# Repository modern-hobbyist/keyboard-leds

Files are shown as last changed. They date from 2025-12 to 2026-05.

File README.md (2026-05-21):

# 🎹 Piano Keyboard LED Visualizer (WIP)

This project is a **custom RP2040-based LED controller** designed to add **reactive RGB lighting** to a piano or MIDI keyboard by reading the incoming **MIDI stream** and driving high-density LED strips.

This is my second iteration of MIDI-driven keyboard LEDs, but the first time going *all in* with a fully custom PCB, power-path management, and an onboard touchscreen UI.

⚠️ **Status:** Work in progress  
Hardware is under active development, firmware and features are evolving, and this README will be updated as the project matures.

---

## ✨ High-Level Overview

- Reads **MIDI input** from a keyboard or computer
- Visualizes notes and velocity using **addressable RGB LEDs**
- Includes a **touchscreen UI** for configuring colors, brightness, and animations
- Designed to safely handle **high LED current** while remaining USB-compliant when connected to a computer

The long-term goal is to make this a flexible platform for experimenting with different LED visualization styles while keeping the hardware robust and reusable.

---

## 🔧 Hardware Overview

### Core Components
- **MCU:** RP2040
- **External Flash:** Winbond **W25Q128JVS** (16 MB)
- **Display:** 2.8″ 320×240 TFT LCD with touch
- **LED Support:**  
  - Designed for ~**1–1.5 m of 144 px/m LED strips**
  - Intended for per-key piano illumination

### USB & Power Architecture
- **USB-C (Data / MIDI / Firmware Flashing)**
- **USB-C (Dedicated LED Power Input)**
- **TPS2121** – automatic power-path switching between USB sources
- **TUSB320** – USB-C CC controller used to determine available current
- **Polyfuses** on both USB inputs for protection

The board is designed to intelligently decide how much LED brightness is safe depending on the power source.

---

## 🎯 Design Goals

- **Dual-mode operation**
  - Plugged into a computer → automatically limit LED current to stay within USB limits (~500 mA)
  - Plugged into a keyboard’s MIDI output + external USB-C PSU → allow much higher LED brightness (~3 A target)
- **Touchscreen UI**
  - Adjust brightness, colors, and animations
  - Switch visualization modes without a computer
- **High LED density support**
  - Enough bandwidth and power to drive dense LED strips cleanly
- **Expandable firmware**
  - External flash provides room for animations, fonts, and UI assets

Exact feature set is still evolving — the focus right now is getting the hardware and power logic correct.

---

## 📌 GPIO Pin Map

### SPI Bus — ILI9341 Display + XPT2046 Touch (shared)
| GPIO | Net | Function |
|---|-----|---|
| 16 | LCD_MISO | SPI MISO |
| 18 | LCD_SCK | SPI clock |
| 19 | LCD_MOSI | SPI MOSI |
| 17 | LCD_CS | ILI9341 chip select |
| 20 | LCD_DC | ILI9341 data/command |
| 21 | LCD_RST | ILI9341 reset |
| 22 | LCD_BL_PWM | Backlight PWM |
| 13 | LCD_T_CS | XPT2046 touch chip select |
| 12 | LCD_T_IRQ | XPT2046 touch interrupt |
| 14 | LCD_SD_CS | SD card chip select (LCD module) |

### I2C Bus — Power Management ICs
| GPIO | Net | Function |
|---|-----|---|
| 4 | SDA | I2C data (TUSB320) |
| 5 | SCL | I2C clock (TUSB320) |

### LEDs & Power Control
| GPIO | Net | Function |
|---|-----|---|
| 6 | RGB3.3 | SK6812 data → level shifter → 5 V strip |
| 3 | DIM_DATA | TPS2121 dimming/current limit control |
| 8 | POWER_INT | Interrupt from power management IC |

### USB
| Signal | Function |
|---|---|
| USB D+ / D− | Data USB-C — MIDI host + firmware flashing |

### QSPI Flash
Managed automatically by MicroPython. Connected to the W25Q128JVS via the RP2040's dedicated QSPI pins (not accessible as general GPIO).

---

## 🧠 Firmware

MicroPython firmware is included in the `firmware/` directory. See [`firmware/README.md`](firmware/README.md) for full setup and flashing instructions.

**Features:**
- USB MIDI host — keyboard plugs directly into the data USB-C port
- SK6812 LED animations: velocity, rainbow, sustain, single color, gradient
- ILI9341 touchscreen UI with scrollable settings menu
- Persistent settings saved to flash (brightness, animation mode, MIDI channel, LED count, etc.)
- Brightness limiting via TPS2121 `DIM_DATA` line based on available power

**Requirements:** MicroPython ≥ 1.24 for RP2040 with `usb.host` support.

---

## 🧩 PCB Review Context

This board uses a few parts that are new to me, particularly for USB-C and power management:

- **TUSB320** – for USB-C current detection
- **TPS2121** – for seamless power-path switching

While I’ve built multiple custom mechanical keyboards, this is my first design combining:
- Dual USB-C inputs
- High LED current
- USB-compliant behavior
- Onboard display + touch

Feedback on **power logic, USB-C usage, and general robustness** is especially appreciated.

---

## 📦 Bill of Materials (BOM)

A complete BOM is included in the repo and reflects the current PCB revision.  
Key highlights:
- RP2040 MCU
- W25Q128JVS external flash
- TPS2121 power mux
- TUSB320 USB-C controller
- SRV05-4 ESD protection
- TFT LCD (ILI9341-based)

⚠️ Component values and footprints may change as the design is reviewed and iterated.

---

## 📸 Media & Updates

I plan to document this project on my **YouTube channel, Modern Hobbyist**, including:
- PCB bring-up
- Power testing
- LED current experiments
- Firmware development

Links will be added as videos are published.

---

## 🤝 Feedback & Contributions

This repo is currently focused on **design review and learning**, but feedback is very welcome.

If you have experience with:
- USB-C power negotiation
- LED power distribution
- RP2040 display pipelines
- MIDI-driven lighting

…I’d love to hear your thoughts.

---

## 📄 License

TBD (will be added once the design stabilizes)

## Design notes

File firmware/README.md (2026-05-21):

# Keyboard LED Firmware

MicroPython firmware for the RP2040-based keyboard LED visualizer.

## Requirements

- **MicroPython ≥ 1.24** for RP2040 with `usb.host` compiled in
  ([download](https://micropython.org/download/RPI_PICO/))
- `neopixel` — built-in to MicroPython
- `framebuf`  — built-in to MicroPython

No third-party libraries are required.

## File layout

```
firmware/
  main.py      Entry point (copy all files to the Pico's root filesystem)
  pins.py      GPIO pin assignments (derived from the KiCad schematic)
  config.py    Settings load/save (persisted to settings.json in flash)
  leds.py      SK6812 LED controller + 5 animation modes
  display.py   ILI9341 SPI display driver (320×240, RGB565)
  touch.py     XPT2046 resistive touch driver
  midi.py      USB MIDI host input + REPL injection helper
  ui.py        Main view + settings menu
```

## Flashing

1. Download the MicroPython UF2 with USB host support for RP2040.
2. Hold BOOTSEL, plug in USB, release — Pico appears as a USB drive.
3. Drag the `.uf2` onto the drive.
4. Use `mpremote` (or Thonny) to copy all `firmware/*.py` to `/`:
   ```sh
   mpremote cp firmware/*.py :
   ```
5. The board will reboot and run `main.py` automatically.

## USB MIDI host

The RP2040 USB port acts as a **USB host**.  Plug your MIDI keyboard's USB
cable directly into the board's data USB-C port.  The firmware discovers the
first USB MIDI class interface automatically.

> **Note:** If your keyboard only has a 5-pin DIN MIDI output, you need a
> USB-MIDI adapter (e.g. Roland UM-ONE) between the DIN connector and the
> board, or connect via a computer running a MIDI bridge.

If `usb.host` is not available in your MicroPython build, the firmware still
boots.  Use the REPL to test without a keyboard:

```python
import midi
midi.inject(0x90, 60, 100)   # note-on middle C, velocity 100
midi.inject(0x80, 60, 0)     # note-off middle C
```

## Touch calibration

Run once after first boot if the touch is inaccurate:

```python
import touch, display, machine
from machine import SPI, Pin
import pins as P
spi = SPI(P.SPI_ID, baudrate=2_000_000, sck=Pin(P.SPI_SCK),
          mosi=Pin(P.SPI_MOSI), miso=Pin(P.SPI_MISO))
display.init(spi)
touch.init(spi)
vals = touch.calibrate()
print(vals)
```

Update `CAL_X_MIN/MAX`, `CAL_Y_MIN/MAX` at the top of `touch.py` with the
printed values.

## Settings

Saved to `settings.json` in the Pico's flash.  Editable at runtime via the
touchscreen Settings menu (tap **Settings** in the top-right corner of the
main screen).

| Key | Default | Description |
|---|---|---|
| `animation` | `velocity`  | `velocity`, `rainbow`, `sustain`, `single`, `gradient` |
| `brightness`  | `80` | LED brightness 0–255 |
| `sustain_ms`  | `500` | Note fade-out duration (sustain mode) |
| `midi_channel`| `0` | 0 = all channels, 1–16 = specific |
| `num_leds` | `144` | Number of LEDs in the strip |
| `note_offset` | `0` | Shift LED mapping ±20 positions |
| `color_h` | `200` | Hue for single-color mode (0–360) |
| `backlight` | `80` | LCD backlight percentage |

## Animation modes

| Mode | Description |
|---|---|
| `velocity` | Key position → hue, velocity → brightness (default) |
| `rainbow`  | Static rainbow; active notes flash white |
| `sustain`  | Notes fade out slowly after release |
| `single` | All active notes use the configured hue |
| `gradient` | Dim colour background; active notes show velocity hue |

MIDI Program Change messages (PC 0–4) also select animation modes in order.

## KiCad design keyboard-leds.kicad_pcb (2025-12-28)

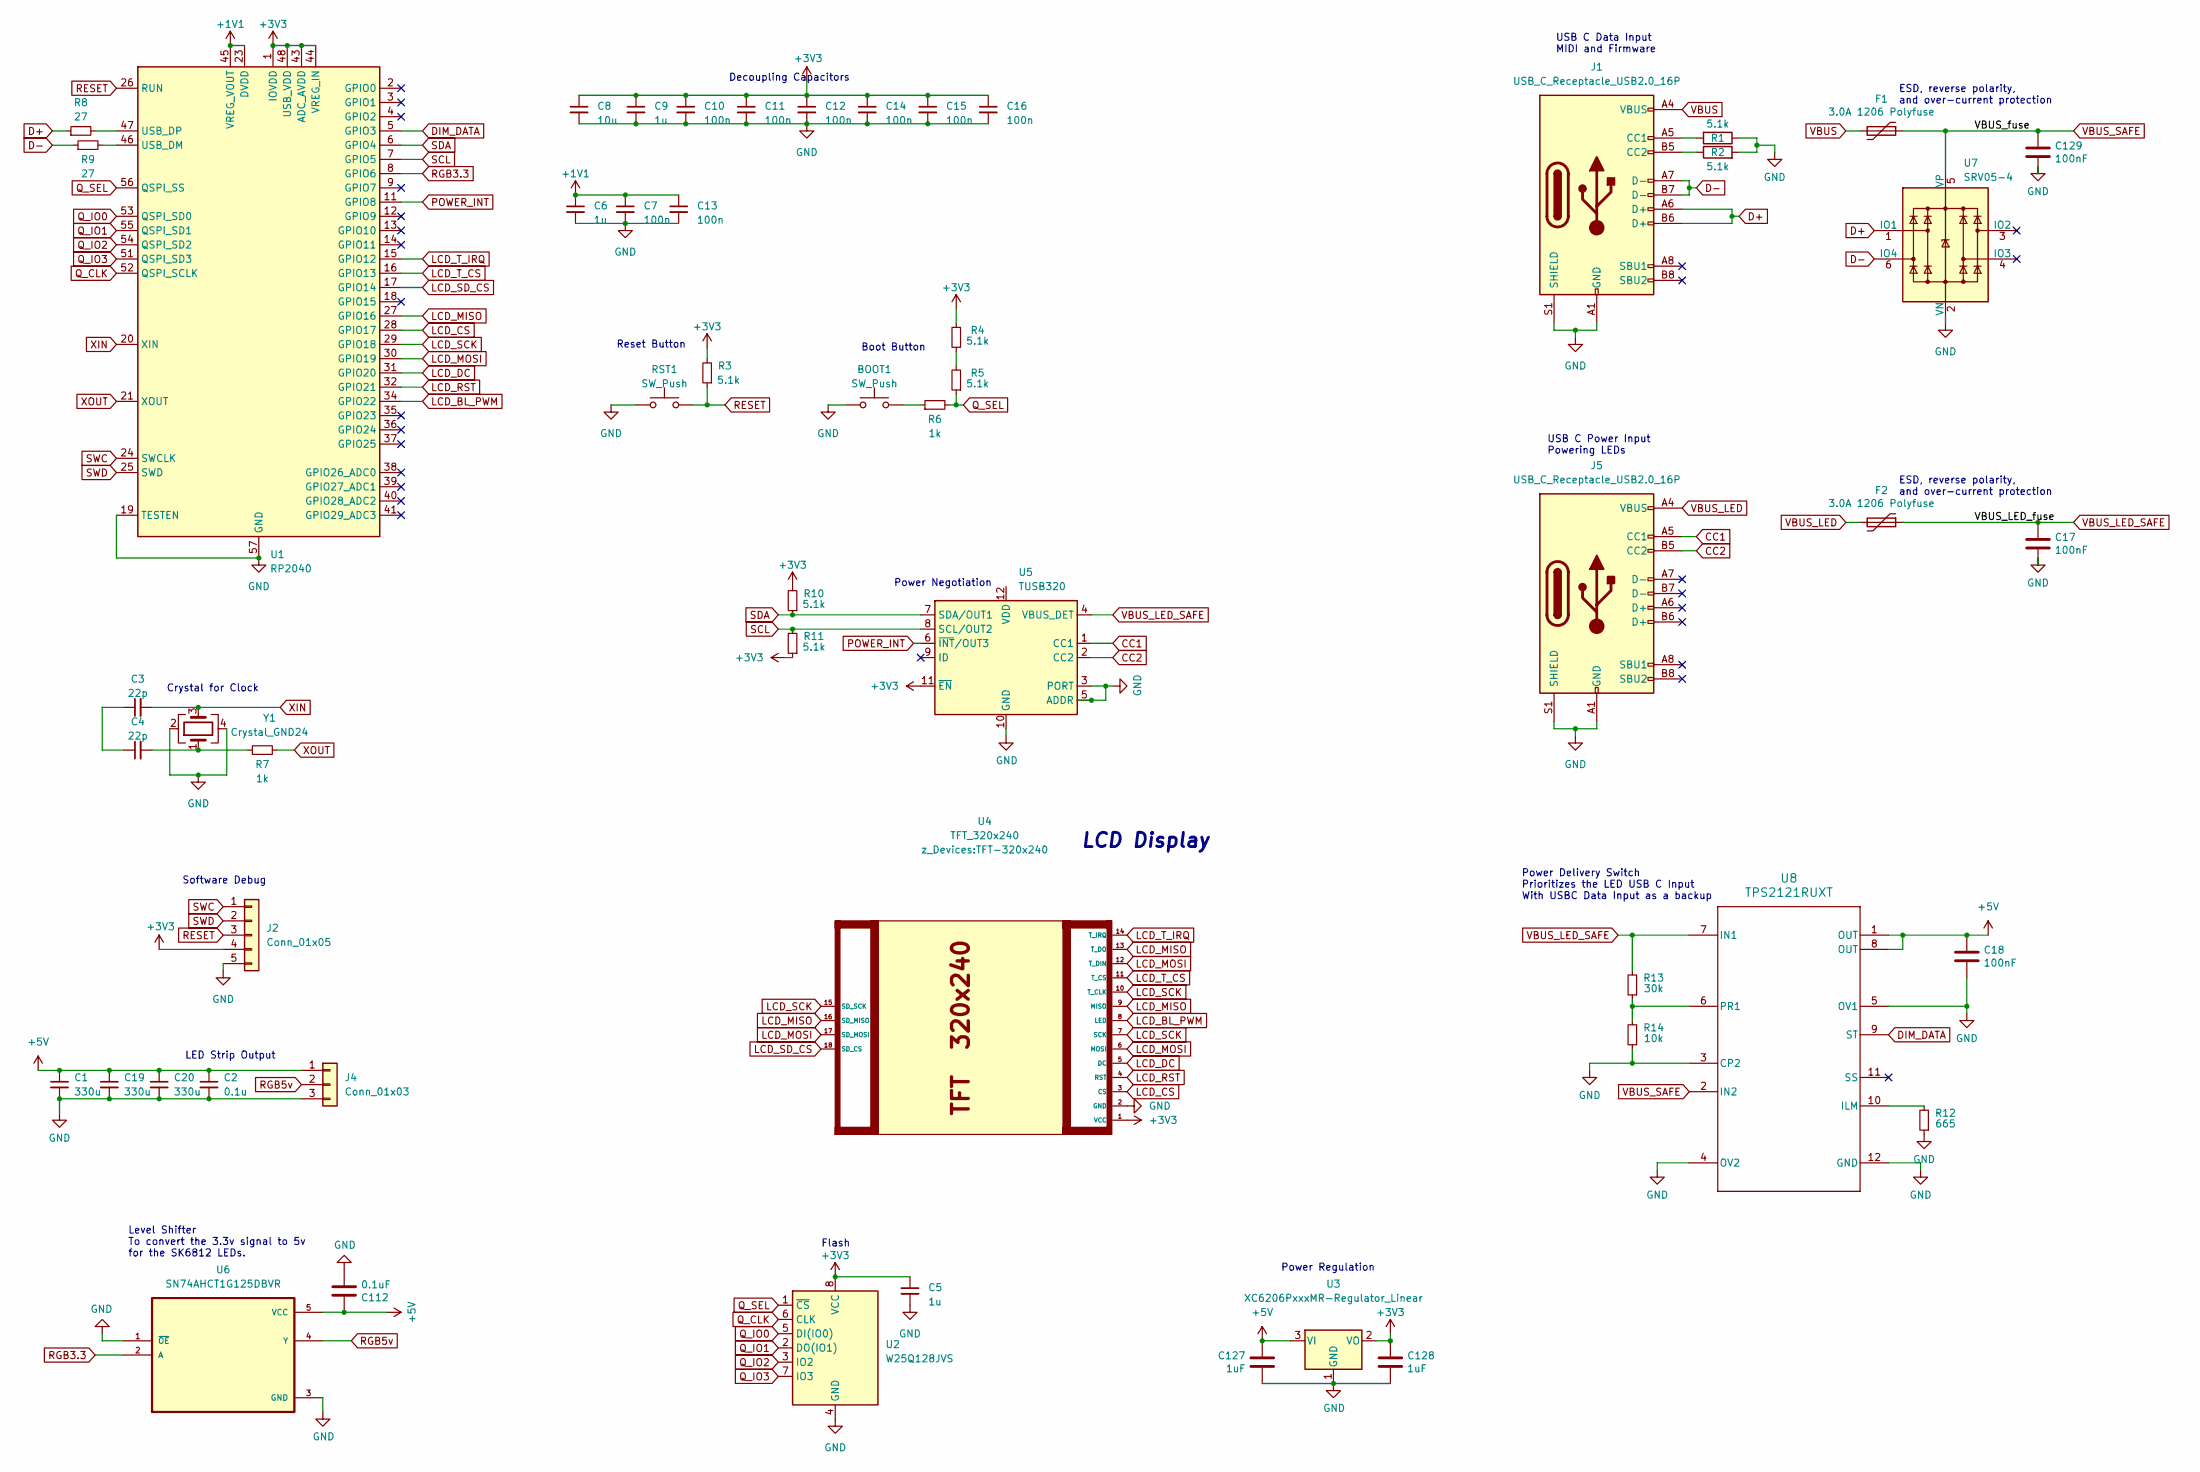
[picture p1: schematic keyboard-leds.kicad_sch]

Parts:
BOOT1: SW_Push; SW_SPST_TL3342
C1, C19, C20: 330u; CP_EIA-7343-31_Kemet-D
C2: 0.1u; C_0603_1608Metric
C3, C4: 22p; C_0402_1005Metric
C5, C6, C9: 1u; C_0402_1005Metric
C7, C10, C11, C12, C13, C14, C15, C16: 100n; C_0402_1005Metric
C8: 10u; C_0603_1608Metric
C17, C18, C129: 100nF; C_0402_1005Metric; LCSC C307331
C112: 0.1uF; C_0402_1005Metric; LCSC C307331
C127, C128: 1uF; C_0402_1005Metric; LCSC C307331
F1, F2: 3.0A 1206 Polyfuse; Fuse_1206_3216Metric
J1, J5: USB_C_Receptacle_USB2.0_16P; USB_C_Receptacle_HRO_TYPE-C-31-M-12
J2: Conn_01x05; PinHeader_1x05_P2.54mm_Vertical
J4: Conn_01x03; JST_XH_S3B-XH-A-1_1x03_P2.50mm_Horizontal
R1, R2, R3, R4, R5, R10, R11: 5.1k; R_0402_1005Metric
R6, R7: 1k; R_0402_1005Metric
R8, R9: 27; R_0402_1005Metric
R12: 665; R_0402_1005Metric
R13: 30k; R_0402_1005Metric
R14: 10k; R_0402_1005Metric
RST1: SW_Push; SW_SPST_TL3342
U1: RP2040; QFN-56-1EP_7x7mm_P0.4mm_EP3.2x3.2mm
U2: W25Q128JVS; SOIC-8_5.23x5.23mm_P1.27mm
U3: XC6206PxxxMR-Regulator_Linear; SOT-23; LCSC C5446
U4: TFT_320x240; TFT-320x240
U5: TUSB320; Texas_X2QFN-12_1.6x1.6mm_P0.4mm
U6: SN74AHCT1G125DBVR; SOT95P280X145-5N
U7: SRV05-4; SOT-23-6-routable
U8: TPS2121RUXT; RUX0012A
Y1: Crystal_GND24; Crystal_SMD_3225-4Pin_3.2x2.5mm

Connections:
+1V1: C6.1, C7.1, C13.1, U1.23 (DVDD), U1.45 (VREG_VOUT), U1.50 (DVDD)
+3V3: C5.1, C8.1, C9.1, C10.1, C11.1, C12.1, C14.1, C15.1, C16.1, C128.1, J2.4, R3.2, R4.2, R10.2, R11.1, U1.1 (IOVDD), U1.10 (IOVDD), U1.22 (IOVDD), U1.33 (IOVDD), U1.42 (IOVDD), U1.43 (ADC_AVDD), U1.44 (VREG_IN), U1.48 (USB_VDD), U1.49 (IOVDD), U2.8 (VCC), U3.2 (VO), U4.1 (VCC), U5.11 (~EN)
+5V: C1.1, C2.1, C18.1, C19.1, C20.1, C112.1, C127.1, J4.1, U3.3 (VI), U6.5 (VCC), U8.1 (OUT), U8.8 (OUT)
CC1: J5.A5 (CC1), U5.1 (CC1)
CC2: J5.B5 (CC2), U5.2 (CC2)
D+: J1.A6 (D+), J1.B6 (D+), R8.1, U7.1 (IO1)
D-: J1.A7 (D-), J1.B7 (D-), R9.1, U7.6 (IO4)
DIM_DATA: U1.5 (GPIO3), U8.9 (ST)
GND: BOOT1.1, C1.2, C2.2, C5.2, C6.2, C7.2, C8.2, C9.2, C10.2, C11.2, C12.2, C13.2, C14.2, C15.2, C16.2, C17.2, C18.2, C19.2, C20.2, C112.2, C127.2, C128.2, C129.2, J1.A1 (GND), J1.A12 (GND), J1.B1 (GND), J1.B12 (GND), J1.S1 (SHIELD), J2.5, J4.3, J5.A1 (GND), J5.A12 (GND), J5.B1 (GND), J5.B12 (GND), J5.S1 (SHIELD), R1.1, R2.2, R12.1, R14.1, RST1.1, U1.19 (TESTEN), U1.57 (GND), U2.4 (GND), U3.1 (GND), U4.2 (GND), U5.3 (PORT), U5.5 (ADDR), U5.10 (GND), U6.1 (~OE), U6.3 (GND), U7.2 (VN), U8.3 (CP2), U8.4 (OV2), U8.5 (OV1), U8.12 (GND), Y1.2, Y1.4
LCD_BL_PWM: U1.34 (GPIO22), U4.8 (LED)
LCD_CS: U1.28 (GPIO17), U4.3 (CS)
LCD_DC: U1.31 (GPIO20), U4.5 (DC)
LCD_MISO: U1.27 (GPIO16), U4.9 (MISO), U4.13 (T_DO), U4.16 (SD_MISO)
LCD_MOSI: U1.30 (GPIO19), U4.6 (MOSI), U4.12 (T_DIN), U4.17 (SD_MOSI)
LCD_RST: U1.32 (GPIO21), U4.4 (RST)
LCD_SCK: U1.29 (GPIO18), U4.7 (SCK), U4.10 (T_CLK), U4.15 (SD_SCK)
LCD_SD_CS: U1.17 (GPIO14), U4.18 (SD_CS)
LCD_T_CS: U1.16 (GPIO13), U4.11 (T_CS)
LCD_T_IRQ: U1.15 (GPIO12), U4.14 (T_IRQ)
unnamed: BOOT1.2, R6.1
unnamed: C3.1, C4.1
unnamed: C4.2, R7.1, Y1.1
unnamed: J1.A5 (CC1), R1.2
unnamed: J1.B5 (CC2), R2.1
unnamed: R4.1, R5.2
unnamed: R9.2, U1.46 (USB_DM)
unnamed: R8.2, U1.47 (USB_DP)
unnamed: R12.2, U8.10 (ILM)
unnamed: R13.1, R14.2, U8.6 (PR1)
POWER_INT: U1.11 (GPIO8), U5.6 (~INT/OUT3)
Q_CLK: U1.52 (QSPI_SCLK), U2.6 (CLK)
Q_IO0: U1.53 (QSPI_SD0), U2.5 (DI(IO0))
Q_IO1: U1.55 (QSPI_SD1), U2.2 (DO(IO1))
Q_IO2: U1.54 (QSPI_SD2), U2.3 (IO2)
Q_IO3: U1.51 (QSPI_SD3), U2.7 (IO3)
Q_SEL: R5.1, R6.2, U1.56 (QSPI_SS), U2.1 (~CS)
RESET: J2.3, R3.1, RST1.2, U1.26 (RUN)
RGB3.3: U1.8 (GPIO6), U6.2 (A)
RGB5v: J4.2, U6.4 (Y)
SCL: R11.2, U1.7 (GPIO5), U5.8 (SCL/OUT2)
SDA: R10.1, U1.6 (GPIO4), U5.7 (SDA/OUT1)
SWC: J2.1, U1.24 (SWCLK)
SWD: J2.2, U1.25 (SWD)
VBUS: F1.2, J1.A4 (VBUS), J1.A9 (VBUS), J1.B4 (VBUS), J1.B9 (VBUS)
VBUS_LED: F2.2, J5.A4 (VBUS), J5.A9 (VBUS), J5.B4 (VBUS), J5.B9 (VBUS)
VBUS_LED_SAFE: C17.1, F2.1, R13.2, U5.4 (VBUS_DET), U8.7 (IN1)
VBUS_SAFE: C129.1, F1.1, U7.5 (VP), U8.2 (IN2)
XIN: C3.2, U1.20 (XIN), Y1.3
XOUT: R7.2, U1.21 (XOUT)

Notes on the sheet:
LCD Display
Power Negotiation
Power Delivery Switch Prioritizes the LED USB C Input With USBC Data Input as a backup
Flash
Reset Button
USB C Data Input MIDI and Firmware
LED Strip Output
Crystal for Clock
Decoupling Capacitors
Level Shifter To convert the 3.3v signal to 5v for the SK6812 LEDs.
Boot Button
USB C Power Input Powering LEDs
Software Debug
ESD, reverse polarity, and over-current protection
Power Regulation

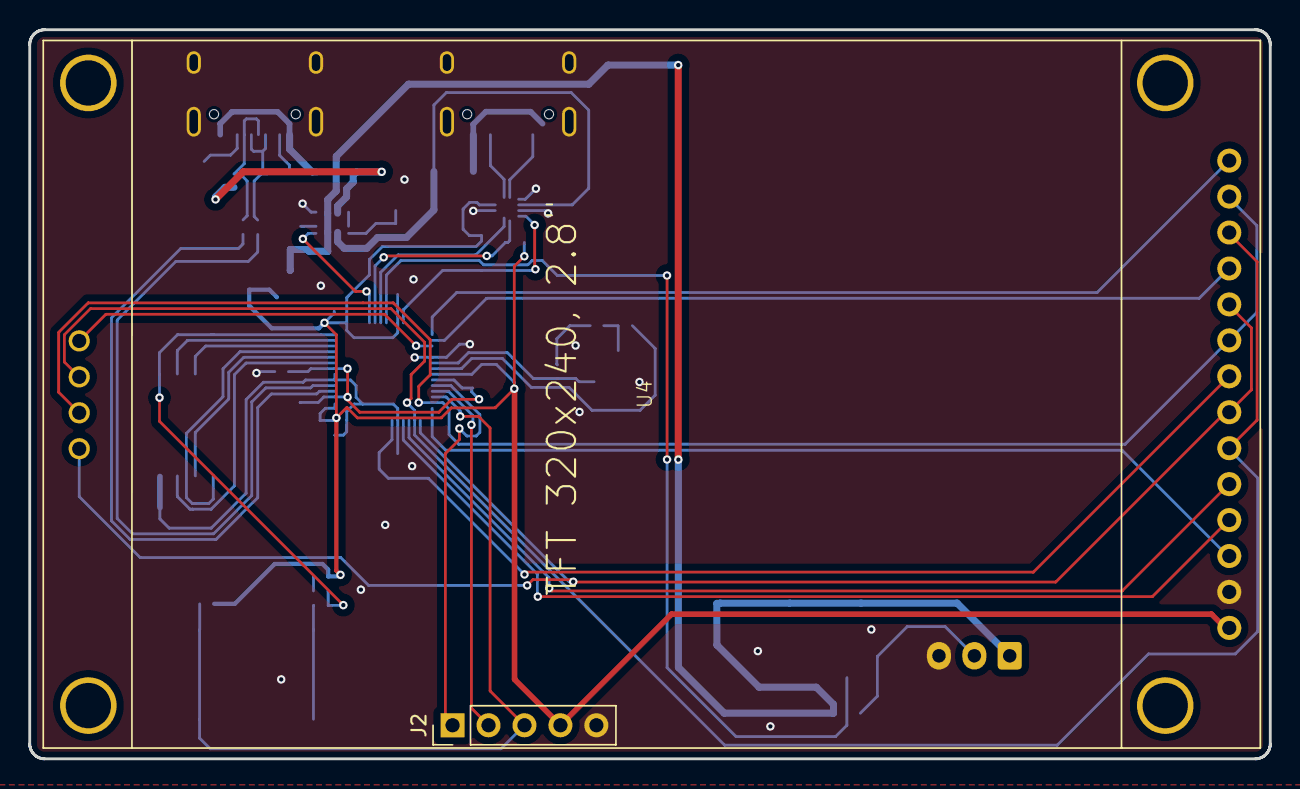
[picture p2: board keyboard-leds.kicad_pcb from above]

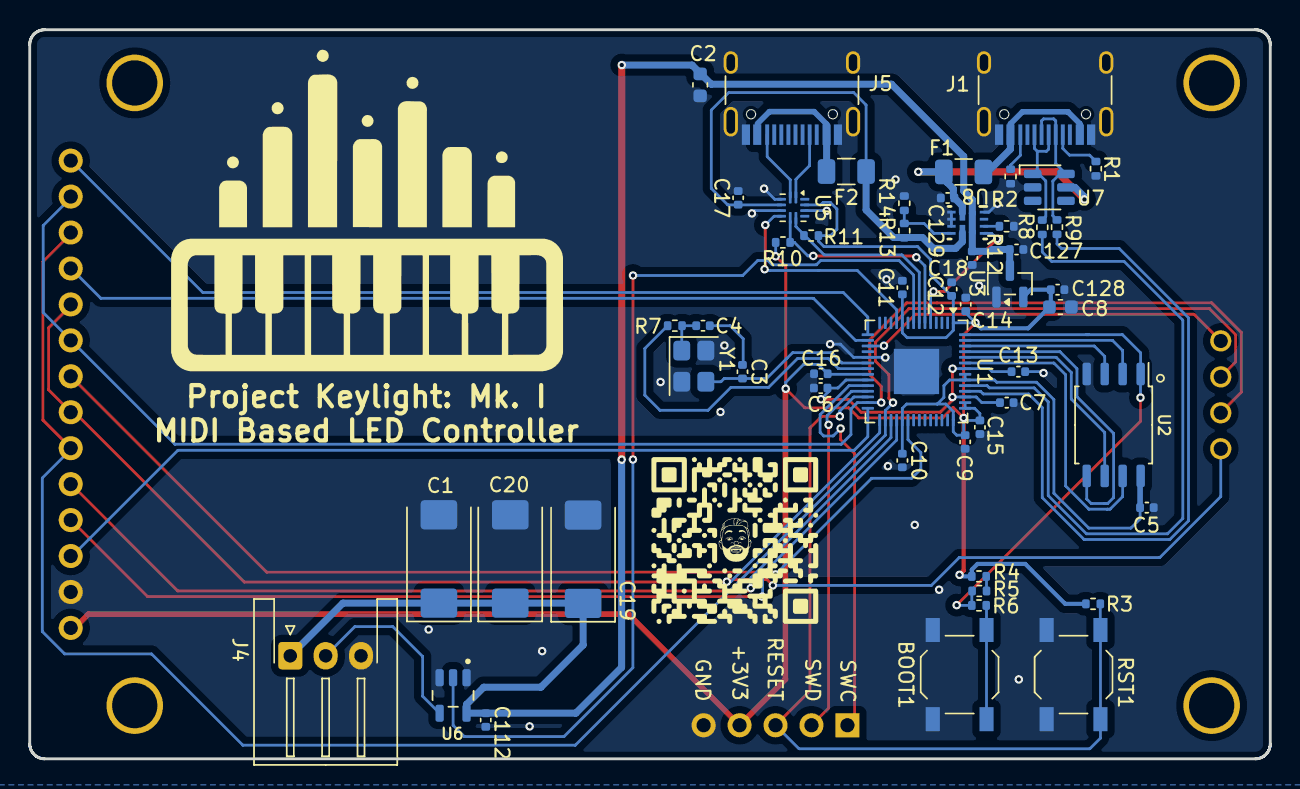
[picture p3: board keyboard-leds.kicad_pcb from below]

Board: 2 copper layers, 87.7 x 51.5 mm, 55 parts (53 on the bottom side), 49 nets.

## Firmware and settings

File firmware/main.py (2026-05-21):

"""
Keyboard LED Visualizer — main entry point.

Boot order:
  1. Load settings from flash
  2. Bring up SPI bus → ILI9341 display
  3. Init XPT2046 touch controller
  4. Init SK6812 LED strip
  5. Start USB MIDI host
  6. Show splash screen + LED test
  7. Enter main loop

USB MIDI host requires MicroPython ≥ 1.24 with usb.host compiled in.
If that module is absent the firmware still boots; use midi.inject() in
the REPL to send notes without a keyboard connected.

Quick REPL test:
  import midi
  midi.inject(0x90, 60, 100)   # note-on C4 vel=100
  midi.inject(0x80, 60, 0)     # note-off C4
"""

import time
from machine import Pin, SPI, I2C, PWM
import pins as P
import config
import leds
import display as d
import touch
import midi
import ui


# ---------------------------------------------------------------------------
# Initialisation
# ---------------------------------------------------------------------------

def _init_spi() -> SPI:
    # Display runs at 40 MHz; touch driver drops to 2 MHz while reading.
    spi = SPI(
        P.SPI_ID,
        baudrate=40_000_000,
        polarity=0,
        phase=0,
        sck=Pin(P.SPI_SCK),
        mosi=Pin(P.SPI_MOSI),
        miso=Pin(P.SPI_MISO),
    )
    return spi


def _init_power():
    """
    Configure the TPS2121 dimming line and set up the power-interrupt pin.

    DIM_DATA (GPIO3) drives the TPS2121 VOUT voltage, which controls maximum
    LED current.  Pull it high (3.3 V) to allow full brightness; the main loop
    can lower it based on POWER_INT feedback from the TUSB320.

    For now, assert high unconditionally and let the user tune via the
    brightness setting.  A proper implementation would read I2C registers from
    the TUSB320 and scale accordingly.
    """
    dim = Pin(P.DIM_DATA, Pin.OUT, value=1)
    power_irq = Pin(P.POWER_INT, Pin.IN, Pin.PULL_UP)
    return dim, power_irq


def _splash():
    bg = d.rgb(10, 10, 30)
    d.fill(bg)
    d.text("Keyboard LEDs",     60, 80,  d.WHITE, bg, scale=2)
    d.text("by Modern Hobbyist", 60, 120, d.GRAY,  bg, scale=1)
    d.text("Booting...",        60, 150, d.GRAY,  bg, scale=1)


# ---------------------------------------------------------------------------
# MIDI callbacks
# ---------------------------------------------------------------------------

def _on_note_on(channel: int, note: int, velocity: int):
    leds.note_on(note, velocity)
    ui.mark_note_on(note)


def _on_note_off(channel: int, note: int, velocity: int):
    leds.note_off(note)
    ui.mark_note_off(note)


def _on_cc(channel: int, control: int, value: int):
    # CC 7 = channel volume → map to overall brightness
    if control == 7:
        config.set("brightness", int(value * 255 / 127))


def _on_program_change(channel: int, program: int):
    # Programs 0-4 select animation modes
    modes = ["velocity", "rainbow", "sustain", "single", "gradient"]
    if program < len(modes):
        config.set("animation", modes[program])


# ---------------------------------------------------------------------------
# Main loop
# ---------------------------------------------------------------------------

_LED_UPDATE_INTERVAL_MS  = 16    # ~60 fps LED refresh
_UI_UPDATE_INTERVAL_MS   = 33    # ~30 fps display refresh
_MIDI_POLL_INTERVAL_MS   = 1     # tight MIDI polling


def run():
    # 1. Settings
    settings = config.load()

    # 2. Power management lines
    _dim, _power_irq = _init_power()

    # 3. Display
    spi = _init_spi()
    d.init(spi)
    _splash()

    # 4. Touch
    touch.init(spi)

    # 5. LEDs
    leds.init()

    # 6. MIDI host
    midi.init(
        on_note_on=_on_note_on,
        on_note_off=_on_note_off,
        on_cc=_on_cc,
        on_program_change=_on_program_change,
        channel_filter=config.get("midi_channel"),
    )

    # 7. Startup test
    leds.test_pattern()
    time.sleep_ms(800)
    ui.force_redraw()

    # 8. Main loop
    t_led = time.ticks_ms()
    t_ui  = time.ticks_ms()

    while True:
        now = time.ticks_ms()

        # MIDI: poll as fast as possible
        midi.poll()

        # LEDs: fixed rate
        if time.ticks_diff(now, t_led) >= _LED_UPDATE_INTERVAL_MS:
            leds.update()
            t_led = now

        # UI: display + touch
        if time.ticks_diff(now, t_ui) >= _UI_UPDATE_INTERVAL_MS:
            ui.update()
            t_ui = now


run()

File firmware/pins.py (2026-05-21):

# Hardware pin assignments derived from keyboard-leds.kicad_sch
# RP2040 GPIO -> net -> function

# SK6812 LED strip (3.3V data -> level shifter -> 5V -> strip)
LED_DATA = 6          # RGB3.3

# Shared SPI bus (ILI9341 display + XPT2046 touch)
SPI_ID   = 0
SPI_SCK  = 18         # LCD_SCK
SPI_MOSI = 19         # LCD_MOSI
SPI_MISO = 16         # LCD_MISO

# ILI9341 display control
LCD_CS   = 17         # LCD_CS
LCD_DC   = 20         # LCD_DC  (data=1, command=0)
LCD_RST  = 21         # LCD_RST
LCD_BL   = 22         # LCD_BL_PWM  (backlight, PWM on slice 3)

# XPT2046 touch controller (same SPI bus, different CS)
TOUCH_CS  = 13        # LCD_T_CS
TOUCH_IRQ = 12        # LCD_T_IRQ

# SD card on LCD module (reserved, not used)
SD_CS = 14            # LCD_SD_CS

# I2C bus (TUSB320 power negotiation IC)
I2C_ID  = 0
I2C_SDA = 4
I2C_SCL = 5

# Power management
POWER_INT = 8         # Interrupt from power IC
DIM_DATA  = 3         # TPS2121 dimming signal

# MIDI note range for a standard 88-key piano
MIDI_NOTE_MIN = 21    # A0
MIDI_NOTE_MAX = 108   # C8
NUM_PIANO_KEYS = 88

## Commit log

2025-12-19 Initial work
    [keyboard-leds.kicad_pcb, keyboard-leds.kicad_sch]
2025-12-19 Cleaned up board a bit
    [keyboard-leds.kicad_pcb]
2025-12-19 Cleaned up footprints
    [keyboard-leds.kicad_pcb, keyboard-leds.kicad_sch]
2025-12-20 Fixed footprint again, 3d model and routing
    [keyboard-leds.kicad_pcb]
2025-12-20 Wired up SD Card, joined SPI devices
    [keyboard-leds.kicad_pcb, keyboard-leds.kicad_sch]
2025-12-20 Added logo and text to PCB
    [keyboard-leds.kicad_pcb]
2025-12-23 Moved led output to other side for better cable management
    [keyboard-leds.kicad_pcb, keyboard-leds.kicad_sch]
2025-12-23 Added qr code
    [keyboard-leds.kicad_pcb]
2026-05-21 Add MicroPython firmware for MIDI-driven LED visualizer (#1)
    Implements full firmware stack for the RP2040-based keyboard LED
    controller: USB MIDI host input, SK6812 LED animations, ILI9341
    touchscreen driver, XPT2046 touch input, and a settings menu UI.
    All GPIO assignments derived from the KiCad schematic.
2026-05-21 Add GPIO pin map and firmware section to README
    Documents all RP2040 pin assignments derived from the KiCad schematic,
    and updates the firmware section to reflect the implemented MicroPython
    firmware rather than the previous placeholder text.
2026-05-21 Remove schematic attribution from GPIO pin map
